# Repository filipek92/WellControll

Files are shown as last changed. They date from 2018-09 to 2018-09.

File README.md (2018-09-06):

View this project on [CADLAB.io](https://cadlab.io/project/1268). 

# WellControll

Board for controlling of well (measuring water level, flow, temperature) over RS485 or USB using ATmega32U4.

Firmware is based on [HardwareSerialRS485 by Michael Jonker](https://github.com/MichaelJonker/HardwareSerialRS485) as multi-master low layer access to shared medium with colision detection.

This board should be integrated into home RS485 network, proxy service to MQTT system is planned for usage of hi level logic service (HomeAssistant....).

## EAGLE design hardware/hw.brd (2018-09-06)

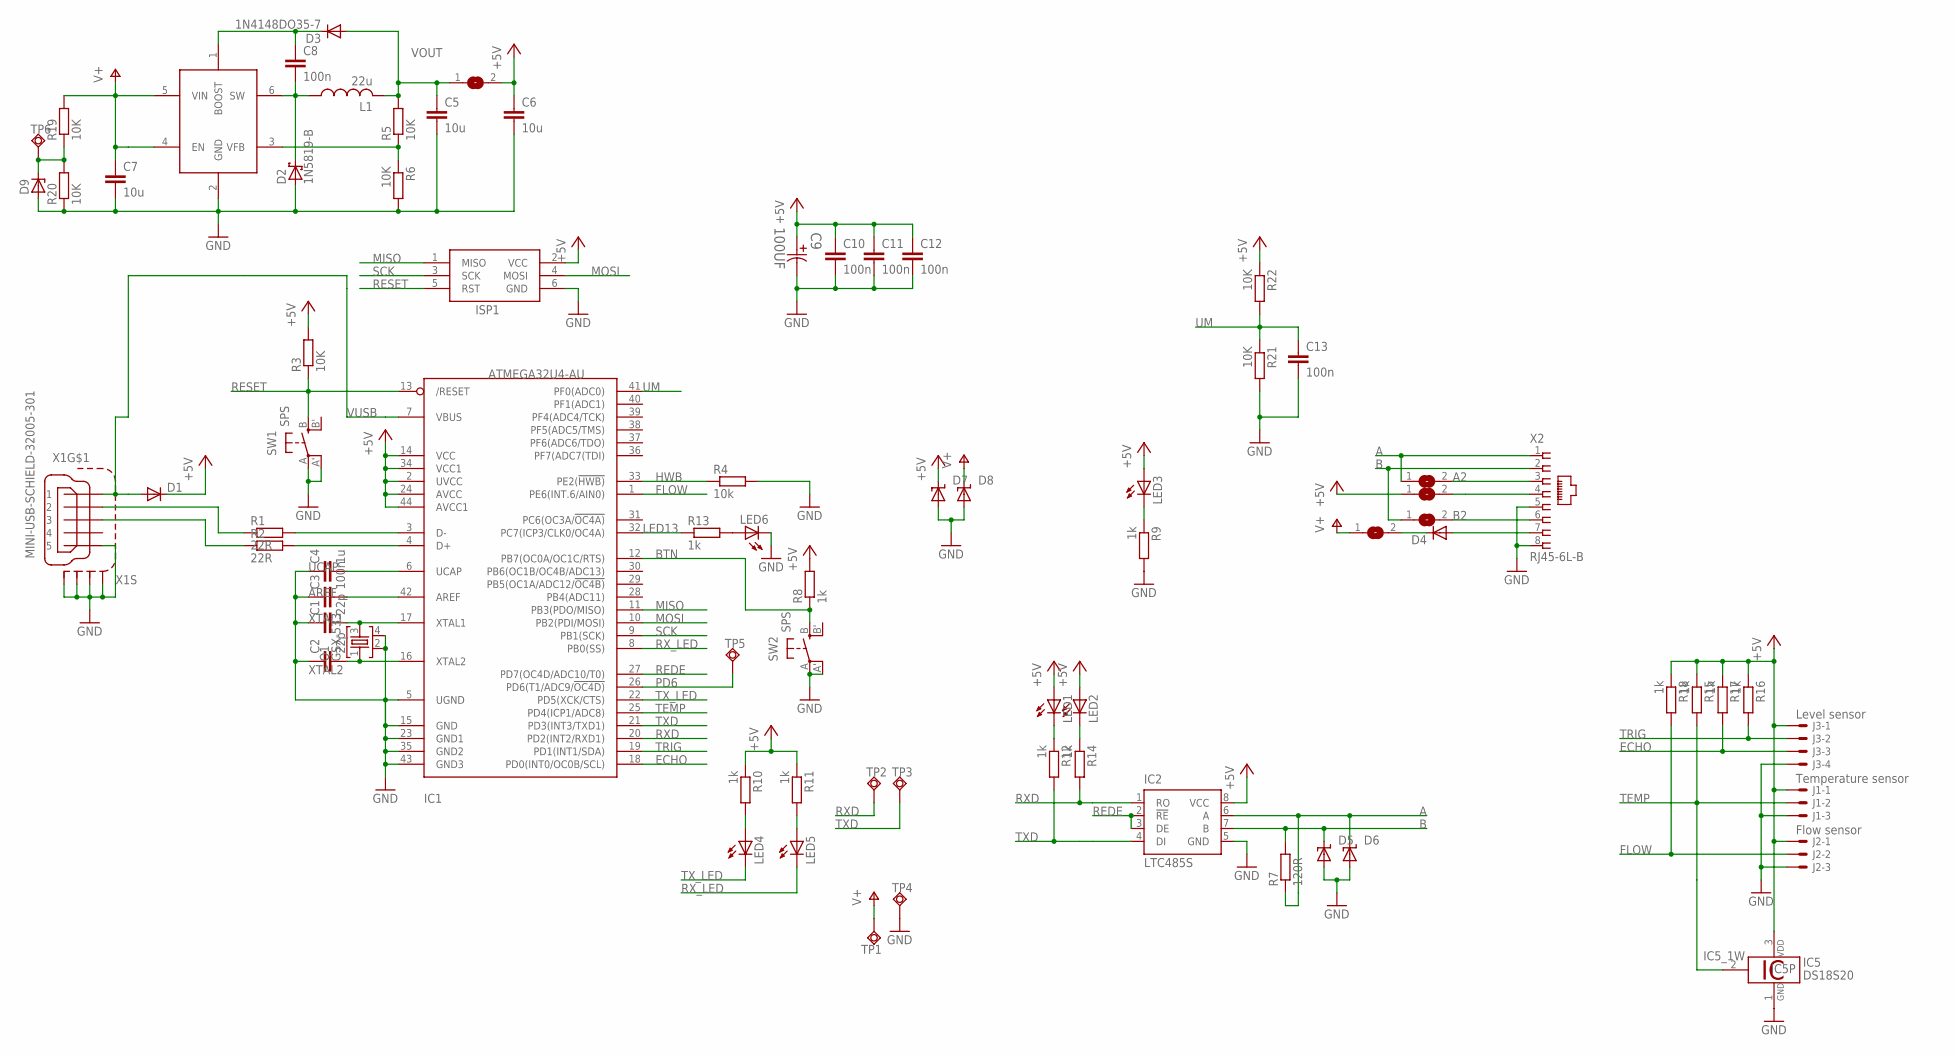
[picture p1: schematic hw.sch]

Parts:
C1, C2: 22p; C0805K
C3, C8, C10, C11, C12, C13: 100n; C0805K
C4: 1u; C0805K
C5, C6, C7: 10u; C0805K
C9: 100UF; CAPAE660X610N
D1: DIODE-MICROMELF-W; MICROMELF-W
D2: 1N5819-B; DO41-7.6
D3: 1N4148DO35-7; DO35-7
D4: DIODE-MINIMELF; MINIMELF
D5, D6, D7, D8: SUPPRESSOR-SMBG; SMBG
D9: ZENER-DIODESMB; SMB
IC1: ATMEGA32U4-AU; TQFP44
IC2: LTC485S; SOIC8
IC3: MCP16301/H; SOT23-6
IC5: DS18S20; TO92-
ISP1: AVRISP-6; AVRISP
J1: Temperature sensor; 6410-03
J2: Flow sensor; 6410-03
J3: Level sensor; 6410-04
L1: 22u; 0207/12
LED1, LED2, LED3, LED4, LED5, LED6: LEDCHIPLED_0805; CHIPLED_0805
Q1: GSX-533; 5032
R1, R2: 22R; M0805
R3, R5, R6, R19, R20, R21, R22: 10K; M0805
R4: 10k; M0805
R7: 120R; M0805
R8, R9, R10, R11, R12, R13, R14, R15, R16, R17, R18: 1k; M0805
SJ1, SJ2, SJ3, SJ4, SJ5: SJ
SW1, SW2: SPS; EVQ-Q2
TP1, TP2, TP3, TP4, TP5, TP6: TPSQTP20SQ; TP20SQ
X1: MINI-USB-SCHIELD-32005-301; 32005-301
X2: RJ45-6L-B; RJ45-NO-SHIELD

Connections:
5V_IN: SJ4.2, X2.4
24V_IN: D4.A, X2.7
+5V: C6.1, C9.1, C10.1, C11.1, C12.1, D1.C, D7.C, IC1.2 (UVCC), IC1.14 (VCC), IC1.24 (AVCC), IC1.34 (VCC1), IC1.44 (AVCC1), IC2.8 (VCC), IC5.3 (VDD), ISP1.2 (VCC), J1.1, J2.1, J3.1, LED1.A, LED2.A, LED3.A, R3.2, R8.2, R10.1, R11.1, R15.1, R16.1, R17.1, R18.1, R22.1, SJ4.1, SJ5.2
A: D6.C, IC2.6 (A), R7.1, SJ1.1, X2.1
A2: SJ1.2, X2.3
AREF: C3.2, IC1.42 (AREF)
B: D5.C, IC2.7 (B), R7.2, SJ2.1, X2.2
B2: SJ2.2, X2.6
BOOST: C8.1, D3.C, IC3.1 (BOOST)
BTN: IC1.12 (PB7(OC0A/OC1C/RTS)), R8.1, SW2.B (S)
D+: IC1.4 (D+), R2.2
D-: IC1.3 (D-), R1.2
ECHO: IC1.18 (PD0(INT0/OC0B/SCL)), J3.3, R17.2
FB: IC3.3 (VFB), R5.1, R6.1
FLOW: IC1.1 (PE6(INT.6/AIN0)), J2.2, R18.2
GND: C1.1, C2.1, C3.1, C4.1, C5.2, C6.2, C7.2, C9.2, C10.2, C11.2, C12.2, C13.2, D2.A, D5.A, D6.A, D7.A, D8.A, D9.A, IC1.5 (UGND), IC1.15 (GND), IC1.23 (GND1), IC1.35 (GND2), IC1.43 (GND3), IC2.5 (GND), IC3.2 (GND), IC5.1 (GND), ISP1.6 (GND), J1.3, J2.3, J3.4, LED6.C, Q1.2 (GND1), Q1.4 (GND2), R4.2, R6.2, R9.2, R20.1, R21.2, SW1.A, SW1.A' (P1), SW2.A, SW2.A' (P1), TP4.TP, X1.5, X1.M1 (S1), X1.M2 (S2), X1.M3 (S3), X1.M4 (S4), X2.5, X2.8
HWB: IC1.33 (PE2(!HWB)), R4.1
LED13: IC1.32 (PC7(ICP3/CLK0/OC4A)), R13.1
MISO: IC1.11 (PB3(PDO/MISO)), ISP1.1 (MISO)
MOSI: IC1.10 (PB2(PDI/MOSI)), ISP1.4 (MOSI)
unnamed: LED4.A, R10.2
unnamed: LED5.A, R11.2
unnamed: D4.C, SJ3.2
unnamed: LED1.C, R12.1
unnamed: LED2.C, R14.1
unnamed: LED3.C, R9.1
unnamed: LED6.A, R13.2
unnamed: D9.C, R19.1, R20.2, TP6.TP
PD6: IC1.26 (PD6(T1/ADC9/!OC4D)), TP5.TP
REDE: IC1.27 (PD7(OC4D/ADC10/T0)), IC2.2 (!RE), IC2.3 (DE)
RESET: IC1.13 (/RESET), ISP1.5 (RST), R3.1, SW1.B (S)
RXD: IC1.20 (PD2(INT2/RXD1)), IC2.1 (RO), R14.2, TP2.TP
RX_LED: IC1.8 (PB0(SS)), LED5.C
SCK: IC1.9 (PB1(SCK)), ISP1.3 (SCK)
SW: C8.2, D2.C, IC3.6 (SW), L1.1
TEMP: IC1.25 (PD4(ICP1/ADC8)), IC5.2 (1W), J1.2, R15.2
TRIG: IC1.19 (PD1(INT1/SDA)), J3.2, R16.2
TXD: IC1.21 (PD3(INT3/TXD1)), IC2.4 (DI), R12.2, TP3.TP
TX_LED: IC1.22 (PD5(XCK/CTS)), LED4.C
UCAP: C4.2, IC1.6 (UCAP)
UM: C13.1, IC1.41 (PF0(ADC0)), R21.1, R22.2
USB+: R2.1, X1.3
USB-: R1.1, X1.2
V+: C7.1, D8.C, IC3.4 (EN), IC3.5 (VIN), R19.2, SJ3.1, TP1.TP
VOUT: C5.1, D3.A, L1.2, R5.2, SJ5.1
VUSB: D1.A, IC1.7 (VBUS), X1.1
XTAL1: C1.2, IC1.17 (XTAL1), Q1.3 (XTAL2)
XTAL2: C2.2, IC1.16 (XTAL2), Q1.1 (XTAL1)

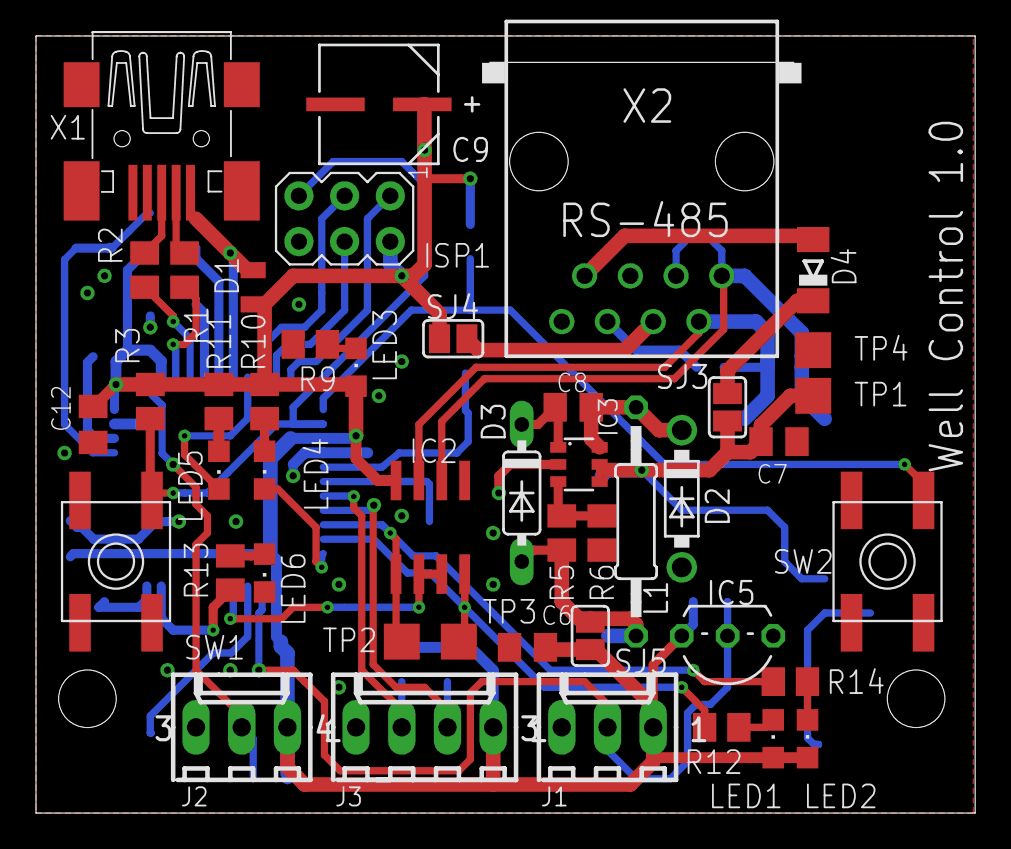
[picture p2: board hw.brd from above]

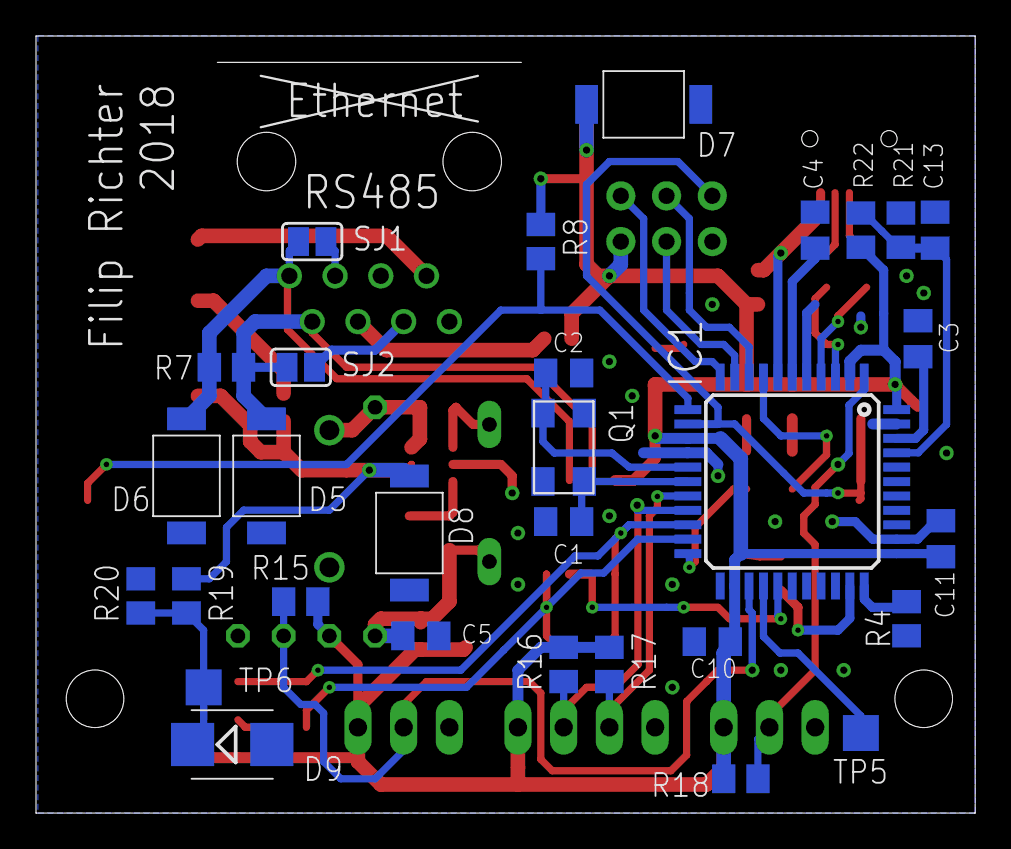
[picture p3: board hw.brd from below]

Board: 2 copper layers, 52.2 x 43.2 mm, 75 parts (30 on the bottom side), 48 nets.

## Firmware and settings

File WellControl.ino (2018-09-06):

#include "HardwareSerialRS485.h"
#include "MessageReader.h"
#include <Bounce2.h>
#include "Build.h"
#include "App.h"

typedef HardwareSerialRS485_1   RS485Class;
typedef MessageReader<32, RS485Class> readerClass;
RS485Class& bus = RS485Class::ourSerialObject;

#define BTN 11
#define LED 13

Bounce debouncer = Bounce(); 

volatile bool measure = false;
volatile bool update = false;

char* myAddressList[]      = {(char*)"S*", 0};

readerClass reader(myAddressList, 20);

Application<readerClass, LED> app(reader);

void setup() { 

  while(!Serial & (millis()<3000));
  Serial1.begin(115200);
  Serial1.println("WellControll");

  bus.begin(9600);

  app.printAliveMessage(bus);
  app.printAliveMessage(Serial);

  initSonar();
  initTemperature();

  pinMode(6, OUTPUT);
  digitalWrite(6,0);
  pinMode(BTN, INPUT);
  debouncer.attach(BTN);
  debouncer.interval(5);
  pinMode(LED, OUTPUT);
}

uint32_t last_measure = 0;
unsigned long buttonPressTimeStamp;
void loop() {

  debouncer.update();
  if(debouncer.fell()){
    app.startMessage();
    bus.print("Learn");
    app.endMessage();
  }

  if(millis()-last_measure > 5000){
    last_measure = millis();
    //sonar_measure();
  }

  if(millis()-last_measure > 1500){
    measure=false;
  }

  if(update){
    app.startMessage();
    Serial1.print("Path: ");
    Serial1.print(path());
    Serial1.print(" cm");
    app.endMessage();
    update=false;
  }

  digitalWrite(LED, measure);

  app.communicate();
}

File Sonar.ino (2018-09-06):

#define MOUNTING_HEIGHT 418.0

#define ECHO 3   
#define TRIGGER 2

volatile uint32_t path_time = 0;

void initSonar(){
  pinMode(ECHO, INPUT);
  pinMode(TRIGGER, OUTPUT);
  attachInterrupt(digitalPinToInterrupt(ECHO), echo, CHANGE);
}

float level(){
  float l = path();
  if(l==0){
    return 0;
  }
  return MOUNTING_HEIGHT - l;   
}

float path(){
  float l = path_time / 58.2;
  if(l>450) return 0;
  if(l<3) return 0;
  return l;
}

void echo(){
  static uint32_t start = 0;
  uint32_t now = micros();
  if(digitalRead(ECHO)){
    start = now;
  }else{
    path_time = now - start;
    measure= false;
    update = true;
  }
}

void sonar_measure(){
    //if(measure) return;
    measure=true;
    digitalWrite(TRIGGER, 0);
    delayMicroseconds(2);
    delay(5);
    digitalWrite(TRIGGER, 1);  
}

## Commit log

2018-08-27 First version kickout
    [hw.brd, hw.sch]
2018-08-27 Set layers visibility
    [hw.brd]
2018-08-28 Changed library of crystal
    [hw.brd, hw.sch]
2018-09-06 Minor fixes
    [hw.brd, hw.sch]
2018-09-06 Files structure changed
    [hw.brd, hw.sch]
